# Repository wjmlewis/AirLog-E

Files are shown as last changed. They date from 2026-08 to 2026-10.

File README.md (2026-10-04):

# AirLog-E
### A battery powered, E-Paper Home Assistant multi-sensor
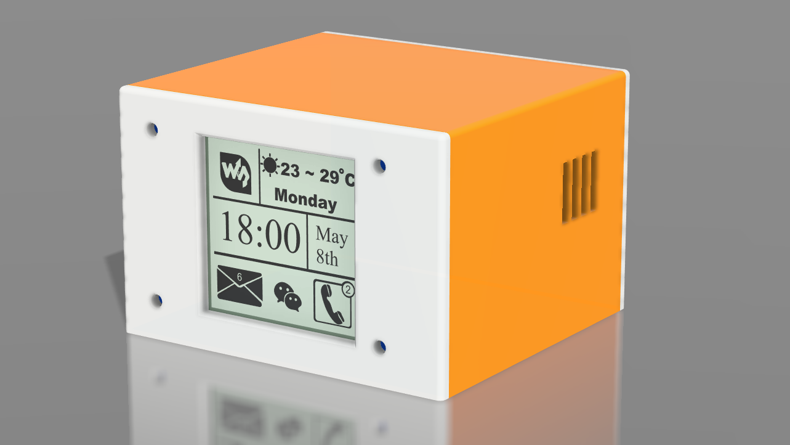
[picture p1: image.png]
fusion360 render

This device is the called the AirLog-E (Beacuse it ***logs*** the ***air*** and has an ***E***-ink display)
## Features
- A **1.54" E-Ink/Paper display** to show current temperature, humidity, and the VOC Index
- It's got 2 sensors. The SHT41 for temp and humidity, and the SGP40 for the VOC Index.
- A large **2000mah Lipo** that can keep the device active and running for a few days on one charge! (can be increased based on deep sleep times)
- It's ability to go into **deep sleep**! At the moment, it wakes up every 90s, updates the sensors, sends it to HA then goes back to sleep after 30s. This can easily be changed to a 5min or even 10min sleep for battery life up to 3 weeks.
- Very **portable**! It's possible to take it with you, connect to your school/office/hotspot's wifi to keep the time updated. In the YAML code, i've predefined **2** networks but this can be expanded.
- If you ever want to change a parameter, you **don't** need to plug it into your computer. ESPhome fully supports OTA **(Over The Air) updates** and I've already written it into the code. You have to use the **ESPhome add-on for Home Assistant** or download **ESPhome with python** to flash the firmware initially.
- **Super accurate** sensors! The SGP-40 (the VOC sensor) utilises the temp and humidity readings from the SHT41 to get a more accurate VOC index.

## E-Ink? What's that??
E-ink or e-paper, is the technology being used in kindles, price tags etc. It only requires a small amount of current to update, and then uses **nothing** when static. You could even unplug the display and the image would stick. These are perfect for small battery powered projects. The only downside to them is their refresh rate. (can take up to **2s** to fully refresh)

## Hardware
(to see the full BOM (bill of materials) click [here](BOM/AirLog-BOMv2.csv))

All the components are enclosed in a 3D printed enclosure which was designed in fusion360. It's split into 3 parts which should be (hopefully) **really easy to assemble and print.** <br> (all 3 parts can fit on a Bambu A1 Mini Build Plate, pictured below)
#
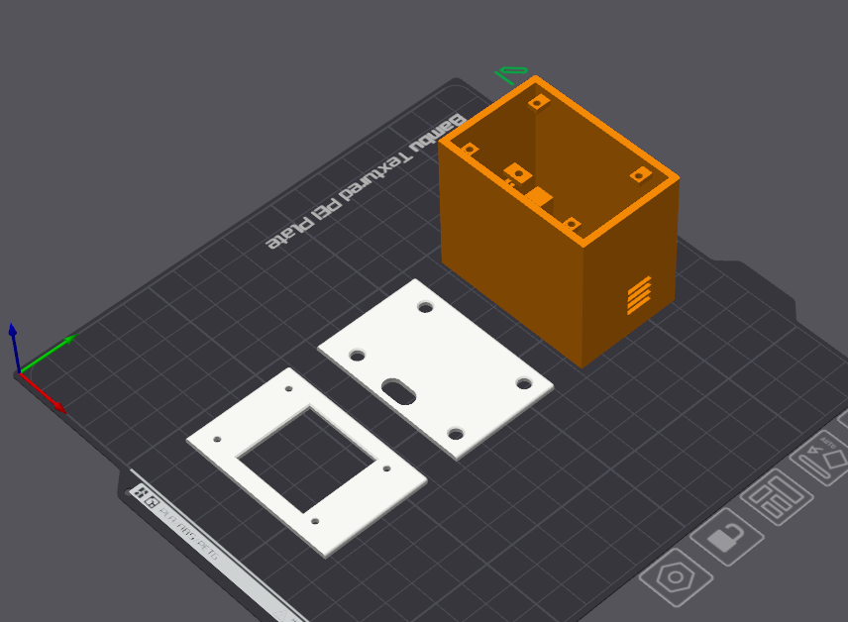
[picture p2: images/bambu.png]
 <br>
#
Theres the **front plate** which attaches to the main section via **M2.5 screws**. (pictured below) The M2.5 screws also hold the display in place.
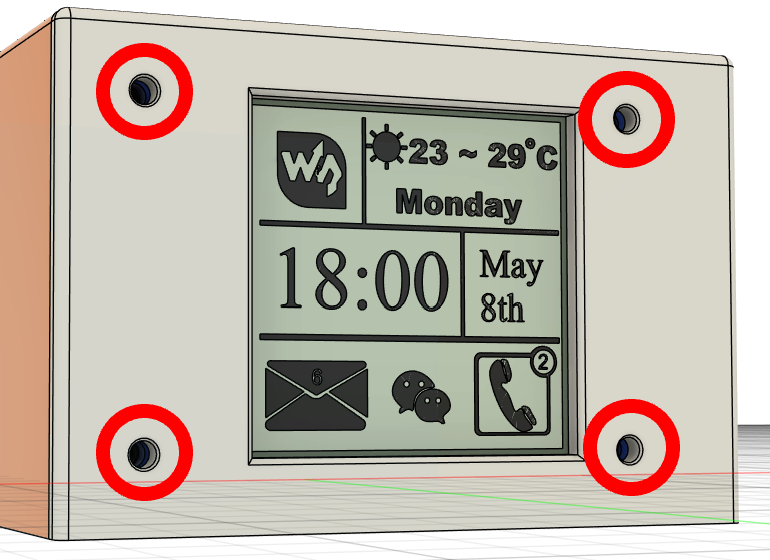
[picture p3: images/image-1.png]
 <br>
#
The **back plate** is connected to the main section via **M3 screws** and **M3 heatset inserts** (pictured below)
#
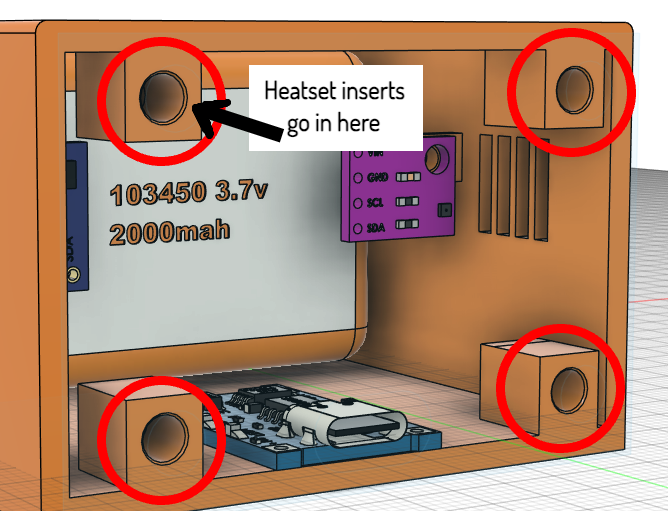
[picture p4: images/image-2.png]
 <br>
#
The **main section** is where all of the electronics are housed. (see photo with battery, front plate, and display removed)
#
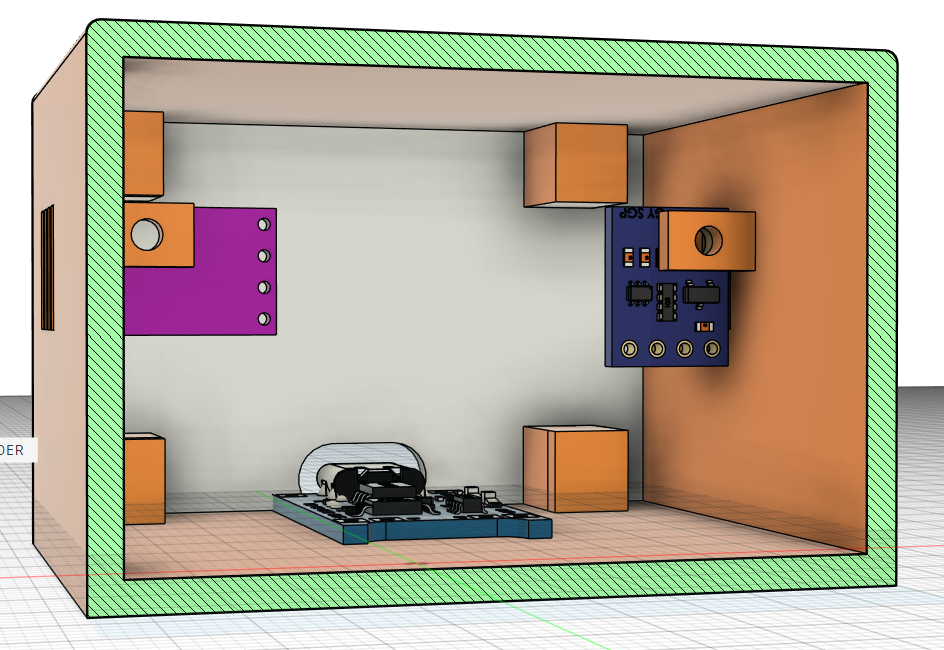
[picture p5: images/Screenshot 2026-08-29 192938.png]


## Electronics
### Here's the breakdown: <br>

### **Microcontroller**
The microcontroller is the **SEEED Studio XIAO ESP32-C6** - it's a super compact microcontroller and perfect for smart home projects as it includes **WiFi, Bluetooth, Zigbee** etc. In the AirLog-E, it doesn't actually have a mounting postion as there are no screw holes and we need access to both sides of the board (for the BAT+ and BAT- pads). This means its **'freefloating'** inside the enclosure, but it would be pretty hard to move as theres 13 wires holding it down! It being freefloating also makes it easier to debug.

### **E-Ink Display**
The E-Ink display by Waveshare and is **1.54"** It's got a 200x200px screen and uses **SPI** to communincate. It can do a partial refresh in as little as **0.3s** and a full refresh in about 2s. Its also got 4 mounting holes in the corner which makes it a breeze to model an enclosure for.

### **2000mah Lipo Battery**
This battery is the perfect size at **10mm x 34mm x 50mm** and has a great capacity.

### **TP4056 Module**
The TP4056 module is **perfect** for this project as it can **charge super fast at 1A**. This means it can charge our battery from empty to full in **just over 2 hours**, and that's once a week!

### **SHT41 Module**
The SHT41 is an amazing little board that gives you **temperature and humidity readings** and communicates via an **I2C bus.**

### **SGP40 Module**
The SGP40 outputs a **VOC Index** which is a scale from **0 to 500** where 100 is a normal baseline and under 100 is cleaner air and over 100 is a **high concentration of VOCs.** It is used as a general air quality sensor. (Great for rooms with 3D printers)

### **M3 Heatset inserts**
Heatset inserts are great beacause it provides a **metal thread** for your screws to go into. I use **4** of these to **connect the back plate to the main section.**

### **26AWG Wire**
This wire is a **great size** as it isn't too big and fiddly to work with and solder but thick enough to carry voltages from the battery. I've chosen 3 colors - **Red, Black and Orange.** They are used for **Power, Ground and Data** respectively. You can use any color as its just for aesthetic purposes.

### **Resistors**
This **entire** project just needs **two** 100kΩ resistors (these should be heatshrunk for a cleaner look and to reduce the risk of a short circuit.) for the voltage divider which steps the battery voltage to a safe enough voltage that the ESP32's GPIO 0 can read.

##
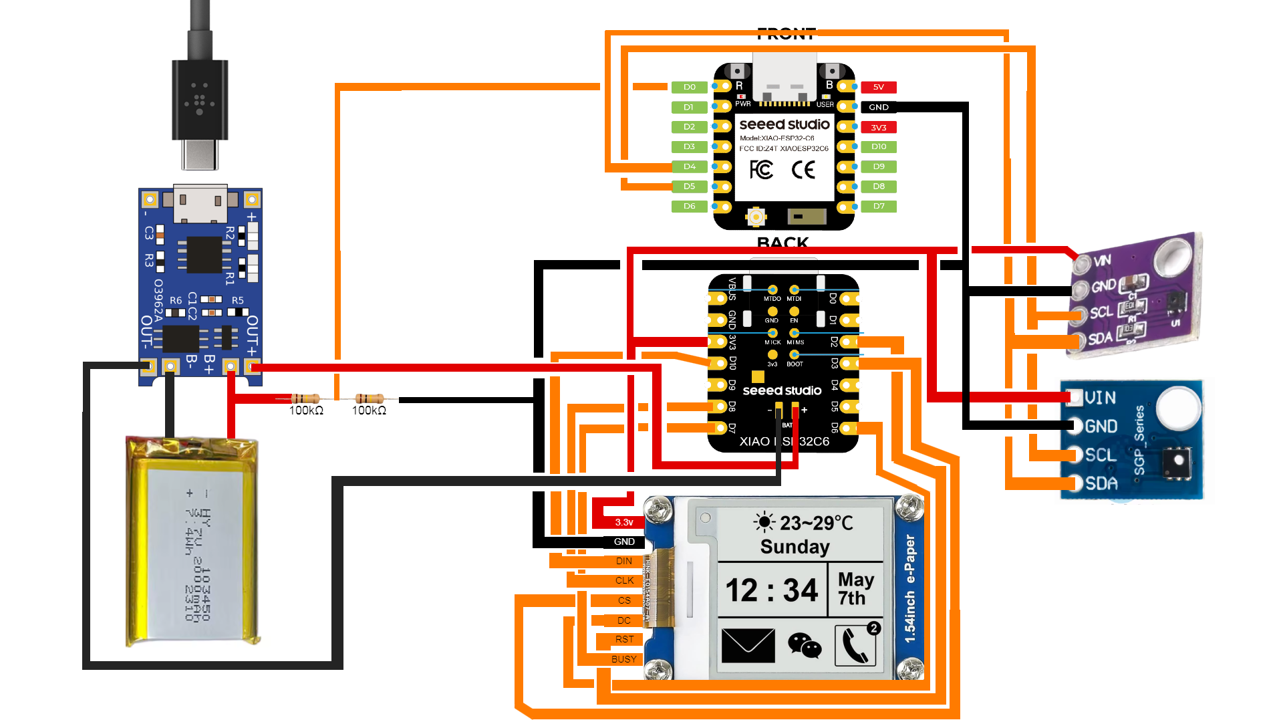
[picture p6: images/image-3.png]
wiring-diagram

**Wiring Diagram** (created in Pixlr-E)

## What else?
There are some things I just **can't** implement into the YAML code before I get my hands on the parts.
These things include:
 - **The time** displayed on screen. This requires NTP (network time protocol) which I can't add yet.
 - **Making the display look futuristic** - At the moment, the sensors are displayed as dynamic text on the screen using the Dosis font. I'm unable to physically see what this looks like yet!

 **Rest assured, I will implement these features as soon as I get the parts!!**

## How did I make this?
I first imported 3D models of the components (from various places such as **grabcad**) into the **Fusion360** project so everything was true to life scale, then created the enclosure around them.

## How can I replicate this project?
First, you'll need Home Assistant.(This can be installed on anything, eg. a Pi, old PC etc) It's not strictly required but then the device won't report data anywhere, you won't be able to push OTA updates, etc. To flash the firmware, either use the Home Assistant Add-on (recommended 100%), or use ESPhome in the command line with python. You also need to adjust secrets.yaml to include your WiFi credentials, API key, encryption key etc. Then 3D print the 3 parts (front plate, main section, back plate, you can find these in the repo) and finally order the components. When everything is in front of you, open up the 3D files **with** the placeholder components so you can see where everything slots and screws in (make sure to refer to the [wiring diagram](<images/AirLog Wiring DiagramV2.png>))

 ## This project was made by William and is for the Hackclub Stardance Challenge!
 ### Credits also go to the ESPhome docs as I couldn't do it without them!

 **AI Usage Declaration**: I used AI as a teaching tool which, for example, explained specific ESPhome components if they weren't heavily documented, helping me fix fusion360 errors etc. I also used it to check if the YAML code will work when components arrive (it should work🤞) Every line of code, diagram, journal, and **this README** was written by me!

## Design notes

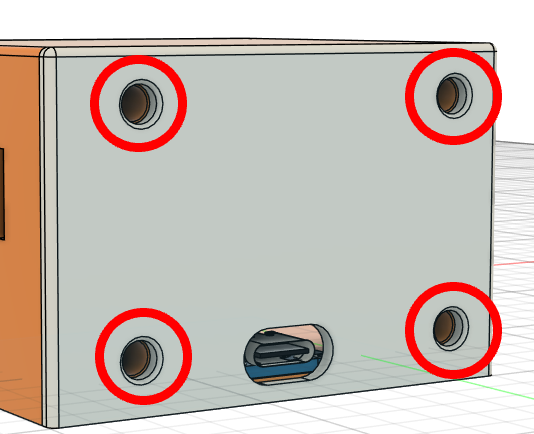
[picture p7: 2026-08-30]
images/backplateredrings.png

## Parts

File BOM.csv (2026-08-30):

Component | Quantity | Price each (USD$) | Price each (GBP£) | Total (USD$) | Total (GBP£) | Source | Link
SEEED ESP-32 C6 (presoldered headers) | 1 | $8.47 | £6.20 | $13.55 (with shipping) | £10.00 (with shipping) | The Pi Hut | https://thepihut.com/products/seeed-xiao-esp32c6
Waveshare 1.54" E-Paper Display | 1 | $20.31 | £14.99 | $20.31 (free shipping) | £14.99 (free shipping) | Amazon | https://www.amazon.co.uk/Waveshare-Module-Electronic-Raspberry-Interface/dp/B0728BJTZC
2000mah LiPo Battery | 1 | $5.41 | £3.99 | $5.41 (free shipping) | £3.99 (free shipping) | Aliexpress | https://www.aliexpress.com/item/1005005614561610.html
TP4056 5v 1A Module (pack of 5) | 1 | $1.56 | £1.15 | $1.56 (free shipping) | £1.15 (free shipping) | Aliexpress | https://www.aliexpress.com/item/1005009325814790.html
SHT41 Module | 1 | $4.05 | £2.99 | $4.05 (free shipping) | £2.99 (free shipping) | Aliexpress | https://www.aliexpress.com/item/1005009925102532.html
SGP40 Module | 1 | $7.65 | £5.65 | $7.65 (free shipping) | £5.65 (free shipping) | Aliexpress | https://www.aliexpress.com/item/1005011540615606.html
M3 Heatset Inserts (100pc, sorry it's the smallest qty I could find!) | 1 | $5.38 | £3.97 | $5.38 (free shipping) | £3.97 (free shipping) | Aliexpress | https://www.aliexpress.com/item/1005006472962973.html
26AWG Wire (2 meters, RED, for POWER cables) | 1 | $0.68 | £0.50 | $0.68 (free shipping) | £0.50 (free shipping) | Aliexpress | https://www.aliexpress.com/item/1005008812047188.html
26AWG Wire (2 meters, BLACK, for GROUND cables) | 1 | $0.68 | £0.50 | $0.68 (free shipping) | £0.50 (free shipping) | Aliexpress | https://www.aliexpress.com/item/1005008812047188.html
26AWG Wire (2 meters, ORANGE, for DATA cables) | 1 | $0.68 | £0.50 | $0.68 (free shipping) | £0.50 (free shipping) | Aliexpress | https://www.aliexpress.com/item/1005008812047188.html
Heatshrink Tubing (already got) | N/A | N/A | N/A | N/A | N/A | My Drawer | N/A
M3 and M2.5 Screws (already got) | N/A | N/A | N/A | N/A | N/A | My Drawer | N/A
Resistors (2x 100k? for the voltage divider) (already got) | N/A | N/A | N/A | N/A | N/A | My Drawer | N/A
 |  |  |  | 59.95 | 44.24

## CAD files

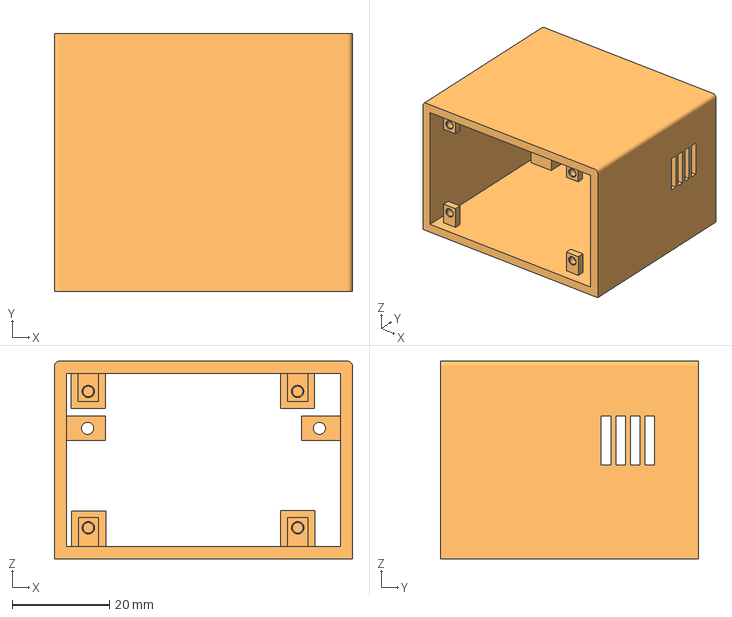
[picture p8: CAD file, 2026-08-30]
3D Files/Individual Parts (3mf)/Main Enclosure.3mf
61.2 x 53.0 x 40.6 mm

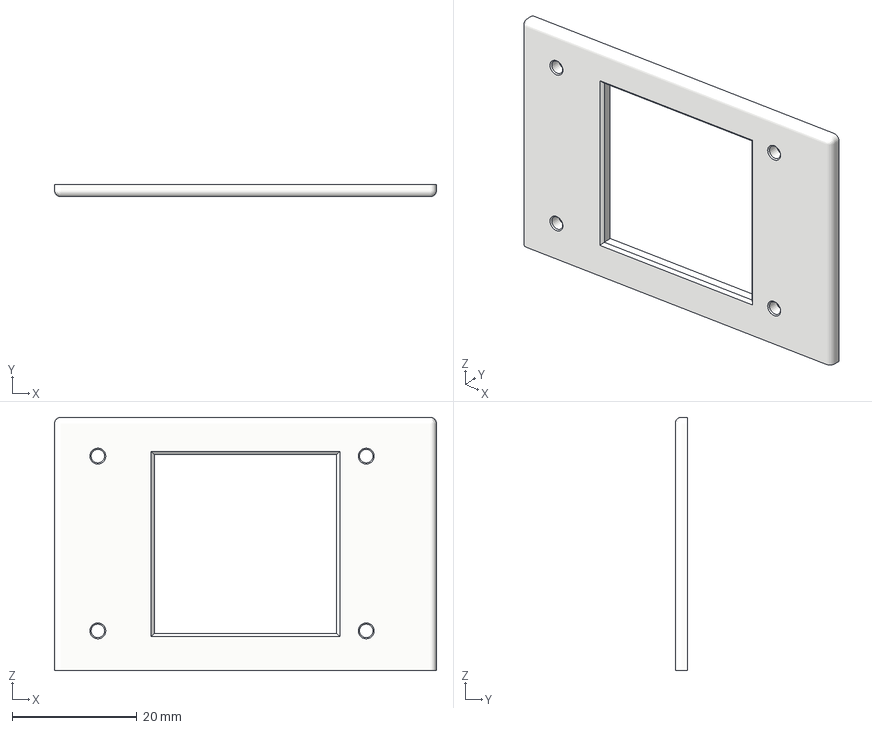
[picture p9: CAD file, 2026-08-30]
3D Files/Individual Parts (3mf)/Front Plate.3mf
61.2 x 2.00 x 40.6 mm

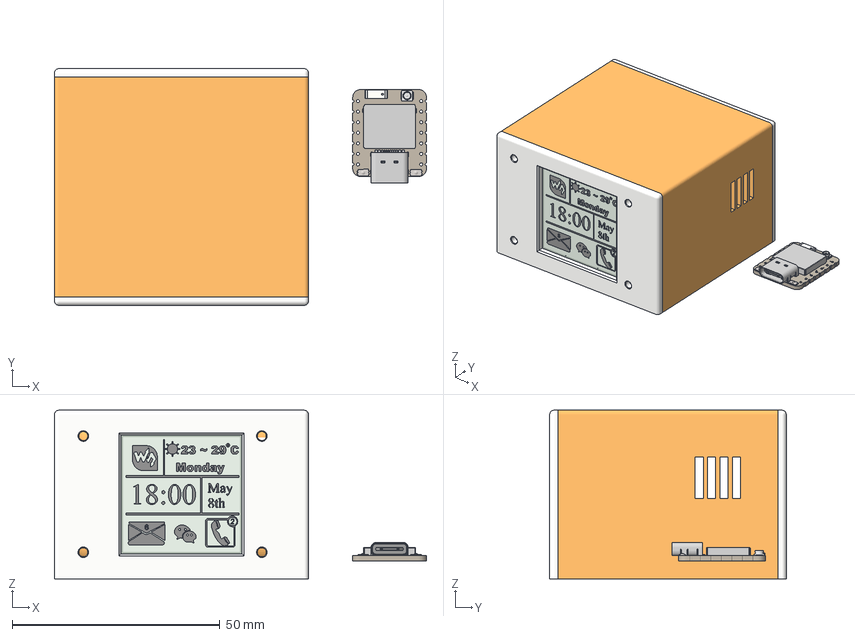
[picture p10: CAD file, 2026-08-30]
3D Files/Project File Models (3mf)/AirLog-E(with-placeholder-components).3mf
89.6 x 57.0 x 40.6 mm
BATTERY PLACEHOLDER
Back Plate
Front Plate
Main Enclosure

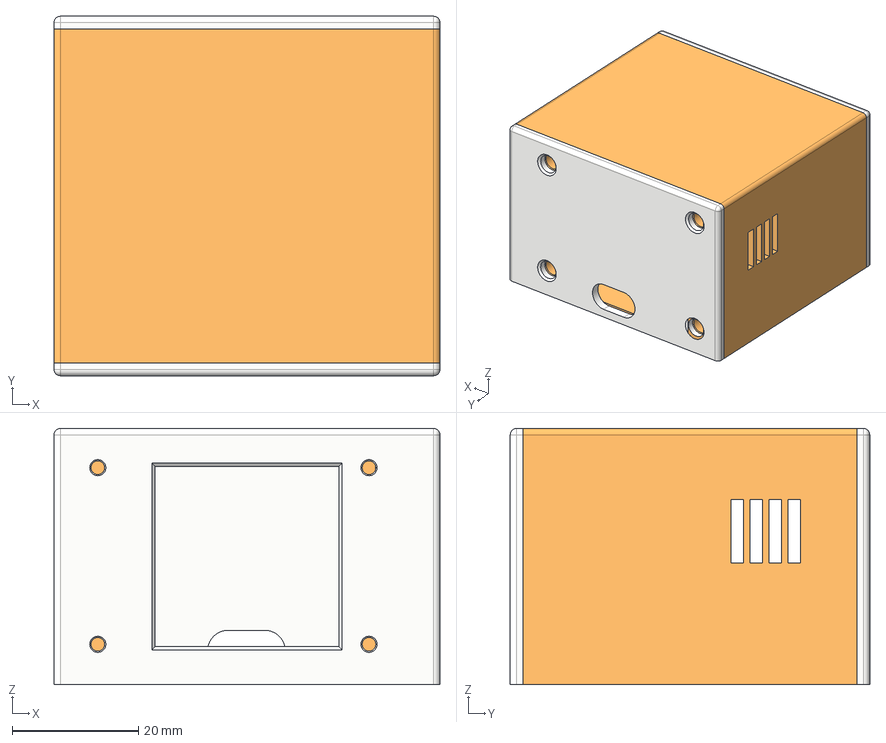
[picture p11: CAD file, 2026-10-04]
3D Files/Project File Models (step)/AirLog-E (together, no-placeholder-components).step
61.2 x 57.0 x 40.6 mm

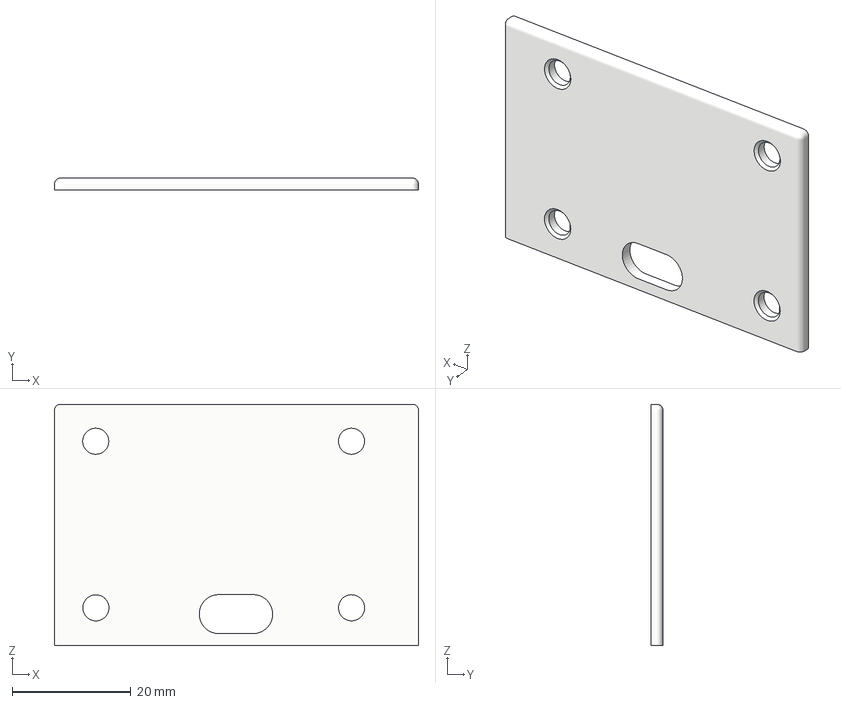
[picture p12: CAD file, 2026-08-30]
3D Files/Individual Parts (3mf)/Back Plate.3mf
61.2 x 2.00 x 40.6 mm

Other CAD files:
3D Files/Fusion Project Files (f3z)/AirLog-E(together, no-placeholder-components).f3d
3D Files/Fusion Project Files (f3z)/AirLog-E(with-placeholder-components).f3z
3D Files/Project File Models (3mf)/AirLog-E (together, no-placeholder-components).3mf

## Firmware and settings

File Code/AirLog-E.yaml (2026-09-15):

esphome:
  name: airlog-e

esp32:
  board: seeed_xiao_esp32c6
  framework:
    type: esp-idf

wifi:
  networks:
    - ssid: !secret home_wifi_ssid
      password: !secret home_wifi_password
    - ssid: !secret hotspot_ssid
      password: !secret hotspot_password

api: 
  port: 6053
  batch_delay: 50ms
  listen_backlog: 2
  max_connections: 6
  max_send_queue: 10
  encryption:
    key: !secret EncryptionKey
  reboot_timeout: 30min

logger:
  level: DEBUG

ota:
  - platform: esphome
    password: !secret "ota_password"

deep_sleep:
  run_duration: 30s
  sleep_duration: 60s

i2c:
  sda: GPIO22
  scl: GPIO23

sensor:
  - platform: sht4x
    update_interval: 10s
    temperature:
      name: "Temperature"
      id: temp_sensor
    humidity:
      name: "Humidity"
      id: humidity_sensor

  - platform: sgp4x
    update_interval: 10s
    voc_index:
      name: "VOC Index"
      id: "voc_index"
    compensation:
      humidity_source: humidity_sensor
      temperature_source: temp_sensor

  - platform: internal_temperature
    name: "Internal Temperature"
    update_interval: 10s
  
  - platform: wifi_signal
    name: "WiFi Signal"
    update_interval: 10s

  - platform: uptime
    name: "Uptime"
    disabled_by_default: true # Stops cluttering HA with sensors you might not need.
    update_interval: 10s

  - platform: adc
    update_interval: 10s
    pin: GPIO0
    name: "Battery Voltage"
    id: battery_voltage
    filters:
      - multiply: 2.0 # we halved the voltage with the voltage divider so this multiplys it by 2 to compensate.
    attenuation: auto

  - platform: template
    name: "Battery Percentage"
    update_interval: 10s
    lambda: |-
      return id (battery_voltage).state;
    filters:
      - calibrate_linear:
        - 3.5 -> 0
        - 4.2 -> 100
      - clamp:
          min_value: 0
          max_value: 100

text_sensor:
  - platform: version
    name: "ESPhome Version"
    disabled_by_default: true

spi:
  mosi_pin: GPIO18
  clk_pin: GPIO19

font:
  - file: "gfonts://Dosis@800"
    id: dosis_extrabold
    size: 18
    glyphs: "0123456789.,:%° abcdefghijklmnopqrstuvwxyzABCDEFGHIJKLMNOPQRSTUVWXYZ"
  
display:
  - platform: waveshare_epaper
    cs_pin: GPIO21
    dc_pin: GPIO16
    busy_pin: GPIO17
    reset_pin: GPIO2
    model: 1.54inv2
    lambda: |-
      it.printf(0, 0, id(dosis_extrabold), "Temp: %.1f°C", id(temp_sensor).state);
      it.printf(0, 30, id(dosis_extrabold), "Hum: %.1f%%", id(humidity_sensor).state);
      it.printf(0, 60, id(dosis_extrabold), "VOC: %.0f", id(voc_index).state);

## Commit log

2026-08-29 Added the BOM
    [Book1.xlsx]
2026-08-29 Added BOM as a .csv
    [AirLog-BOM.csv]
2026-08-29 (new BOM with resistors)
    [AirLog-BOMv2.csv]
2026-08-29 Delete AirLog-BOM.csv
    (replaced with V2)
    [AirLog-BOM.csv]
2026-08-29 Wiring Diagram!
2026-08-30 Update AirLog-BOMv2.csv with new components
    [AirLog-BOMv2.csv]
2026-08-30 Rename AirLog Wiring DiagramV2.png to images/AirLog Wiring DiagramV2.png
2026-08-30 Update BOM with new prices and components
    [AirLog-BOMv2.csv]
2026-08-30 adjust resistor line
    Updated README.md to correct formatting and improve clarity.
2026-08-30 renamed AirLog-BOMv2.csv to BOM.csv and moved it to root!
    [BOM.csv]
2026-10-04 Added 'How did I make this?' to the README and added to the assembly guide!
2026-10-23 Enhance AirLog-E configuration with RTC and scripts
    Updated the AirLog-E configuration to include RTC variables, improved boot scripts, and refined sensor configurations.
